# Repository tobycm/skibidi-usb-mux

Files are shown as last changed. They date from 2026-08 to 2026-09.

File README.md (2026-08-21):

# Skibidi USB Mux

A simple USB mux with 2 upstream USB C ports and 3 downstream USB A ports and 1 downstream USB C port. Powered by the onsemi FSUSB42MUX mux and WCH CH334P usb hub IC.

View PCB on KiCanvas (https://kicanvas.org/?repo=https://github.com/tobycm/skibidi-usb-mux/tree/main/pcb)
View BOM in iBOM

## PCB

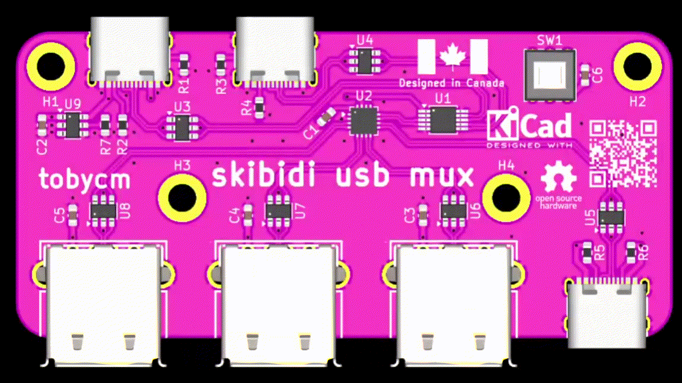
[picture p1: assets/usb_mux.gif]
usb mux gif


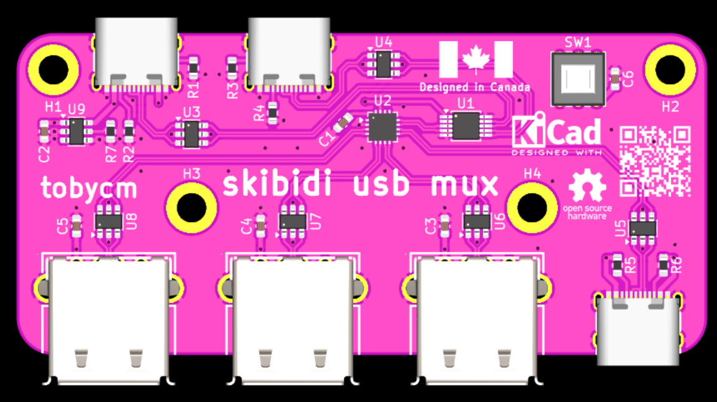
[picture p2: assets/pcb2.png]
pcb2


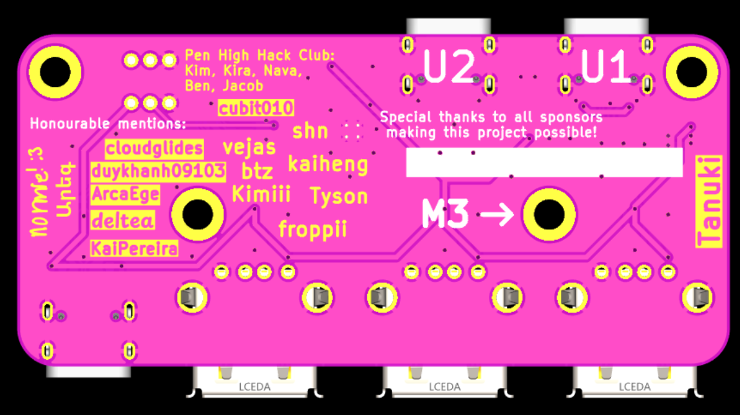
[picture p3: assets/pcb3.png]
pcb3


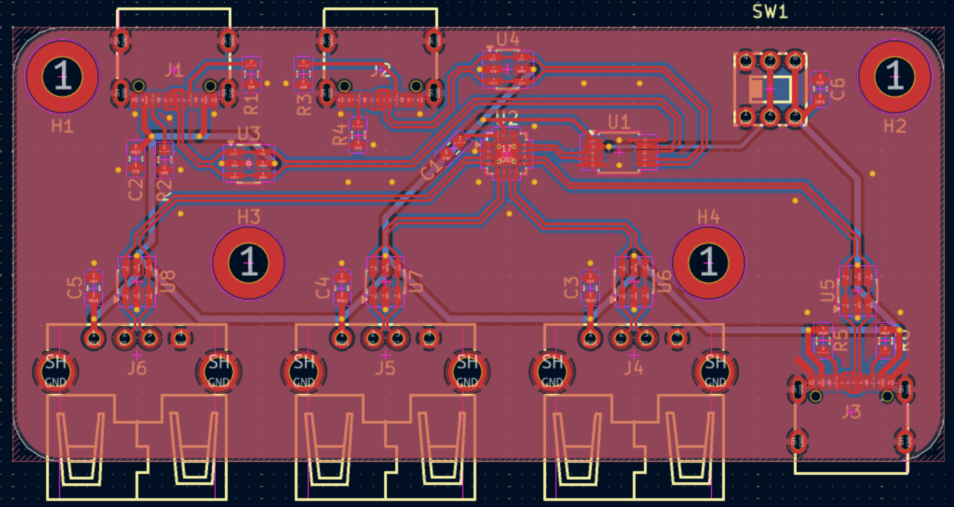
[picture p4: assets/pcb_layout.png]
pcb layout


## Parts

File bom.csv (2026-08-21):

Description | Quantity | Part # | Unit price | Extended Price USD | Product Link
100nF ±10% 50V Ceramic Capacitor X7R 0603 | 50 | CC0603KRX7R9BB104 | 0.0175 | 0.88 | https://www.lcsc.com/product-detail/C14663.html
10uF ±20% 25V Ceramic Capacitor X5R 0603 | 60 | CL10A106MA8NRNC | 0.0798 | 4.79 | https://www.lcsc.com/product-detail/C96446.html
USB-C (USB TYPE-C) Receptacle Connector 16 Position Surface Mount, Right Angle | 40 | TYPE-C 16PIN 2MD(073) | 0.0707 | 2.83 | https://www.lcsc.com/product-detail/C2765186.html
USB-A (USB TYPE-A) Receptacle Connector 4 Position Right Angle | 30 | AF 90 WJDG | 0.0487 | 1.46 | https://www.lcsc.com/product-detail/C456018.html
5.1k? ±1% 100mW 0603 Thick Film Resistor | 100 | FRC0603F5101TS | 0.0025 | 0.25 | https://www.lcsc.com/product-detail/C2907044.html
56k? ±1% 100mW 0603 Thick Film Resistor | 100 | 0603WAF5602T5E | 0.005 | 0.50 | https://www.lcsc.com/product-detail/C23206.html
Pushbutton Switch DPDT Rectangular Plunger | 10 | PS-5850A-6PL | 0.2048 | 2.05 | https://www.lcsc.com/product-detail/C963201.html
3V~4.4V 720MHz 3.9? 2:1 MSOP-10 Analog Switches - Special Purpose RoHS | 10 | FSUSB42MUX | 0.3187 | 3.19 | https://www.lcsc.com/product-detail/C11355.html
4 480Mbps USB 2.0 QFN-16(3x3) Interface Controllers RoHS | 10 | CH334P | 0.3658 | 3.66 | https://www.lcsc.com/product-detail/C5373042.html
12VC Clamp 6A Ipp ESD DIODE SOT-23-6 | 100 | USBLC6-2SC6 | 0.0355 | 3.55 | https://www.lcsc.com/product-detail/C2827654.html
24k? ±1% 100mW 0603 Thick Film Resistor | 100 | FRC0603F2402TS | 0.0027 | 0.27 | https://www.lcsc.com/product-detail/C2930081.html
LCSC Shipping |  | LCSC Shipping | 12.62 | 12.62 | https://www.lcsc.com/
PCB |  | PCB | 5 | 5 | https://jlcpcb.com/
Stencil |  | Stencil | 3.07 | 3.07 | https://jlcpcb.com/
JLCPCB Shipping |  | JLCPCB Shipping | 9.5 | 9.5 | https://jlcpcb.com/
 |  | Total: |  | 53.61

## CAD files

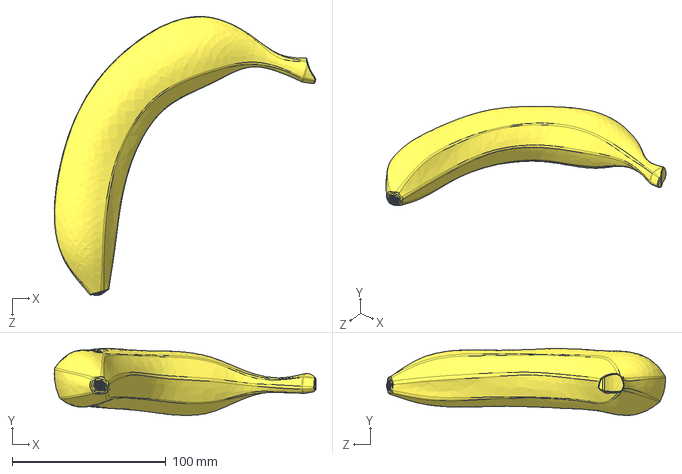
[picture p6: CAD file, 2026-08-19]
cad/Banana.STEP
170.1 x 43.7 x 181.5 mm

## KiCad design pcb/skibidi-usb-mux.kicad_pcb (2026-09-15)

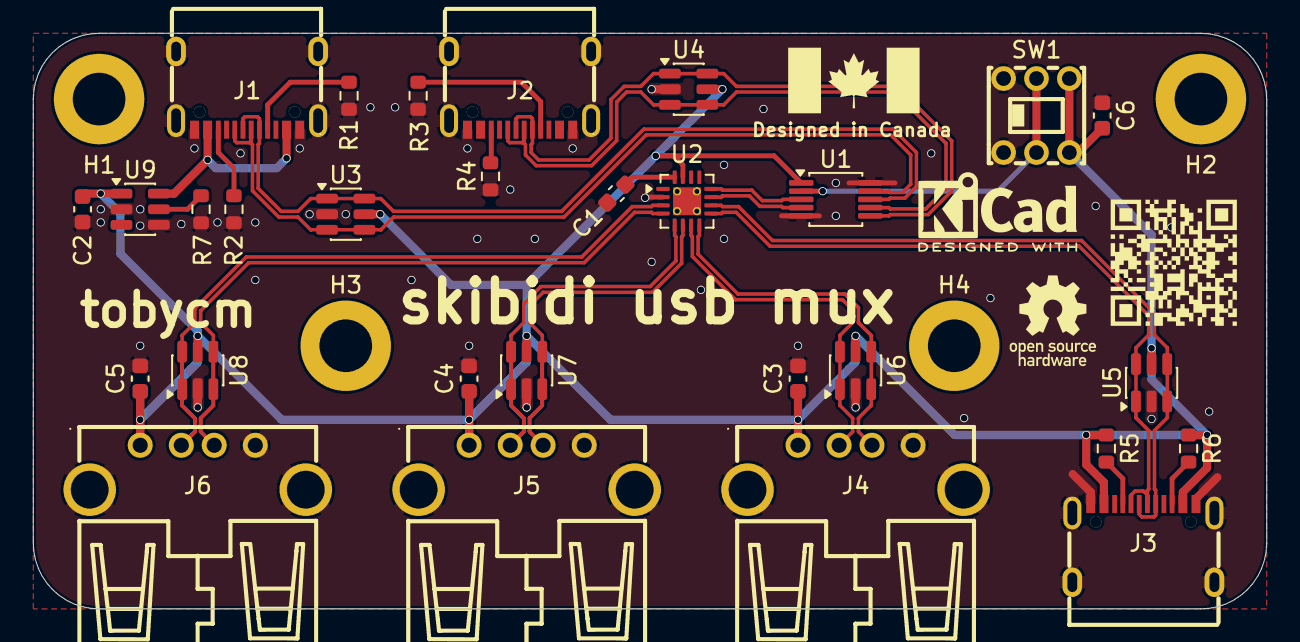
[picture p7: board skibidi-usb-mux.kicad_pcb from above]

Board: 2 copper layers, 75.0 x 35.0 mm, 33 parts (0 on the bottom side), 26 nets.

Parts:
C1, C6: 100n; C_0603_1608Metric
C2, C3, C4, C5: 10u; C_0603_1608Metric
H1, H2, H3, H4: MountingHole; MountingHole_3.2mm_M3_ISO14580_Pad
J1, J2, J3: USB_C_Receptacle_USB2.0_14P; USB-C-SMD_TYPE-C-16PIN-2MD-073
J4, J5, J6: USB_A; USB-A-TH_AF-WJDG
R1, R2, R3, R4: 5.1k; R_0603_1608Metric
R5, R6: 56k; R_0603_1608Metric
R7: 24k; R_0603_1608Metric
SW1: PS-5850A-6PL; SW-TH_6P-L5.8-W5.8-P2.00-LS4.5-BL_1
U1: FSUSB42MUX; MSOP-10_3x3mm_P0.5mm
U2: CH334P; QFN-16-1EP_3x3mm_P0.5mm_EP1.7x1.7mm_ThermalVias
U3, U4, U5, U6, U7, U8: USBLC6-2SC6; SOT-23-6
U9: CH217A; SOT-23-6

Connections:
/1D+: J3.A6 (D+), J3.B6 (D+), U2.10 (DP1), U5.3 (I/O2), U5.4 (I/O2)
/1D-: J3.A7 (D-), J3.B7 (D-), U2.9 (DM1), U5.1 (I/O1), U5.6 (I/O1)
/2D+: J4.3 (D+), U2.8 (DP2), U6.3 (I/O2), U6.4 (I/O2)
/2D-: J4.2 (D-), U2.7 (DM2), U6.1 (I/O1), U6.6 (I/O1)
/3D+: J5.3 (D+), U2.6 (DP3), U7.3 (I/O2), U7.4 (I/O2)
/3D-: J5.2 (D-), U2.5 (DM3), U7.1 (I/O1), U7.6 (I/O1)
/4D+: J6.3 (D+), U2.4 (DP4), U8.3 (I/O2), U8.4 (I/O2)
/4D-: J6.2 (D-), U2.3 (DM4), U8.1 (I/O1), U8.6 (I/O1)
/SEL: SW1.2, SW1.5, U1.2 (SEL)
/U1D+: J2.A6 (D+), J2.B6 (D+), U1.7 (HSD1+), U4.3 (I/O2), U4.4 (I/O2)
/U1D-: J2.A7 (D-), J2.B7 (D-), U1.6 (HSD1-), U4.1 (I/O1), U4.6 (I/O1)
/U2D+: J1.A6 (D+), J1.B6 (D+), U1.9 (HSD2+), U3.3 (I/O2), U3.4 (I/O2)
/U2D-: J1.A7 (D-), J1.B7 (D-), U1.8 (HSD2-), U3.1 (I/O1), U3.6 (I/O1)
/UD+: U1.3 (D+), U2.12 (DPU)
/UD-: U1.4 (D-), U2.11 (DMU)
GND: C1.1, C2.1, C3.1, C4.1, C5.1, C6.1, J1.A1 (GND), J1.B1 (GND), J1.SH (SHIELD), J2.A1 (GND), J2.B1 (GND), J2.SH (SHIELD), J3.A1 (GND), J3.B1 (GND), J3.SH (SHIELD), J4.4 (GND), J4.SH (Shield), J5.4 (GND), J5.SH (Shield), J6.4 (GND), J6.SH (Shield), R1.1, R2.1, R3.1, R4.1, R7.1, SW1.1, SW1.4, U1.5 (GND), U1.10 (~OE), U2.2 (XI), U2.17 (GND), U3.2 (GND), U4.2 (GND), U5.2 (GND), U6.2 (GND), U7.2 (GND), U8.2 (GND), U9.2 (GND), U9.4 (EN#)
unnamed: J1.A5 (CC1), R1.2
unnamed: J1.B5 (CC2), R2.2
unnamed: J2.A5 (CC1), R3.2
unnamed: J2.B5 (CC2), R4.2
unnamed: J3.A5 (CC1), R5.2
unnamed: J3.B5 (CC2), R6.2
unnamed: C1.2, U2.16 (VDD33)
unnamed: R7.2, U9.5 (ISET)
unnamed: J1.A4 (VBUS), J1.B4 (VBUS), U9.6 (VIN)
VBUS: C2.2, C3.2, C4.2, C5.2, C6.2, J3.A4 (VBUS), J3.B4 (VBUS), J4.1 (VBUS), J5.1 (VBUS), J6.1 (VBUS), R5.1, R6.1, SW1.3, SW1.6, U1.1 (VCC), U2.15 (V5), U3.5 (VBUS), U4.5 (VBUS), U5.5 (VBUS), U6.5 (VBUS), U7.5 (VBUS), U8.5 (VBUS), U9.1 (VOUT)

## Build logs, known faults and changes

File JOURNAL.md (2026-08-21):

---
title: "Skibidi USB Mux"
github: "https://github.com/tobycm/skibidi-usb-mux"
description: "A simple USB mux with 2 upstream USB C ports and 3 downstream USB A ports and 1 downstream USB C port."
created_at: "2026-08-20"
---

# August 19: Compiled a mental part list and started on schematic

Ended up with using the onsemi FSUSB42MUX for switching between 2 data pairs and using my favourite USB hub IC, the WCH CH334P, to expand to more ports.

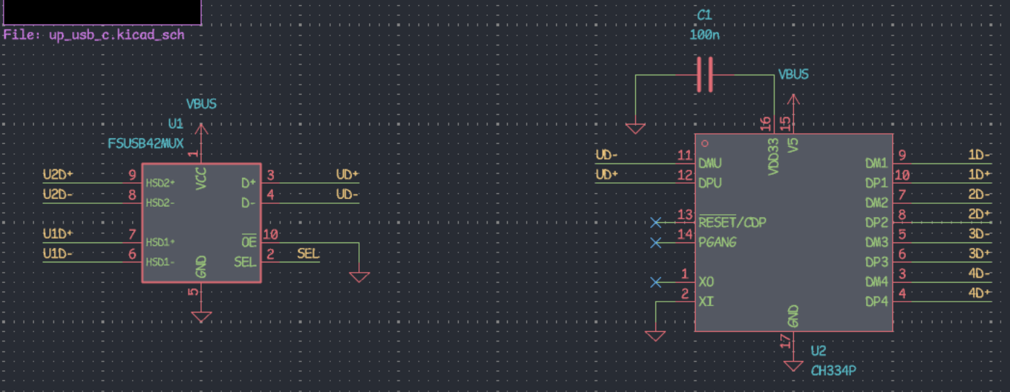
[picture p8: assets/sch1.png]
sch1


**Total time spent: 1h**

# August 20: Completed the schematic and PCB layout and routing

The truth table for the state of the mux:

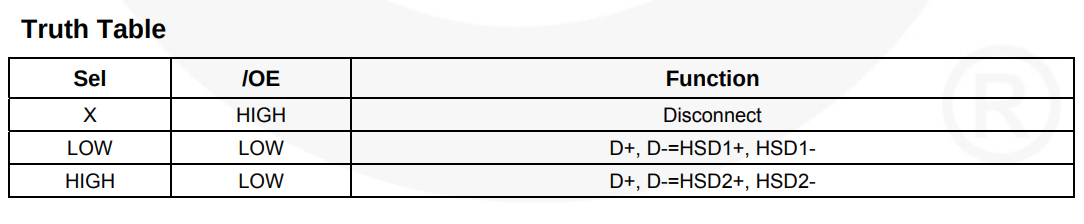
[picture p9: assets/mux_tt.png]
mux truth table


i realizd a latching switch is the best for this, so i picked the [G-Switch PS-5850A-6PL](https://www.lcsc.com/product-detail/C963201.html)

Final PCB look:

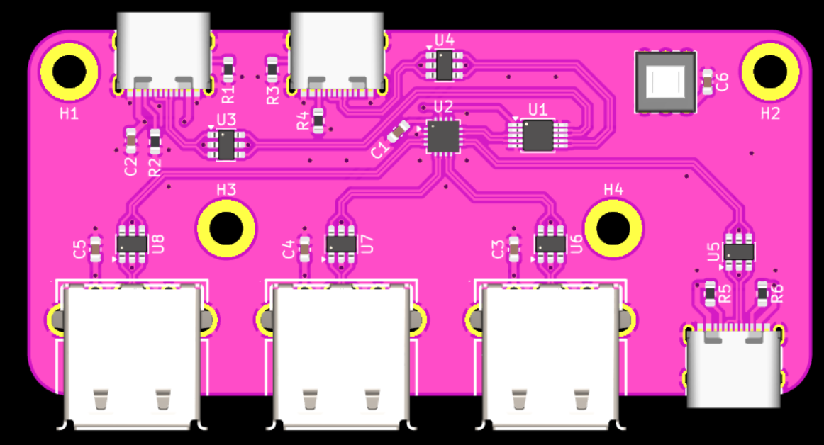
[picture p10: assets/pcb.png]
pcb


**Total time spent: 1h**

# August 20 night: Decorated PCB

Shoutout to everyone who agreed to be on my PCB 🔥🔥🔥

pcb2
pcb3

**Total time spent: 2h**

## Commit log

2026-08-21 add more mentions and art
    [skibidi-usb-mux-CuBottom.gbr, skibidi-usb-mux-CuTop.gbr, skibidi-usb-mux-EdgeCuts.gbr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]
2026-09-15 update ibom and pcb
    [skibidi-usb-mux.kicad_pcb]
